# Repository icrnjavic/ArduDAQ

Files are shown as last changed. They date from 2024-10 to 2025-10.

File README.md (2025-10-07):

# ArduDAQ

<p float="left">
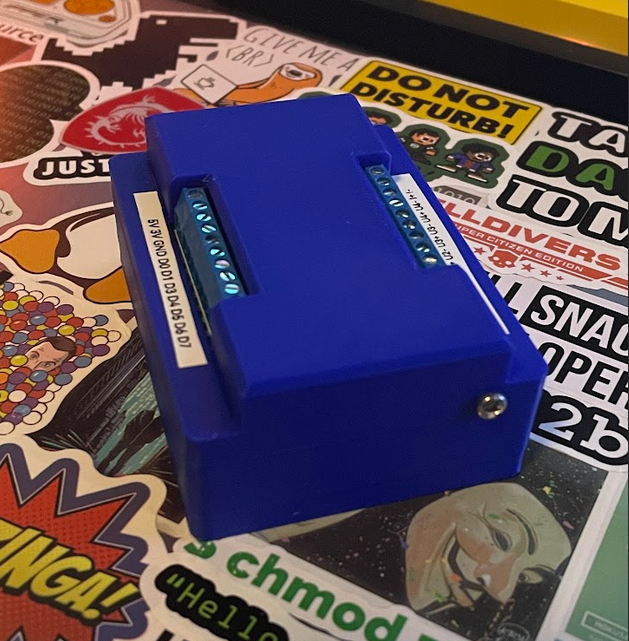
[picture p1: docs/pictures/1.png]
  
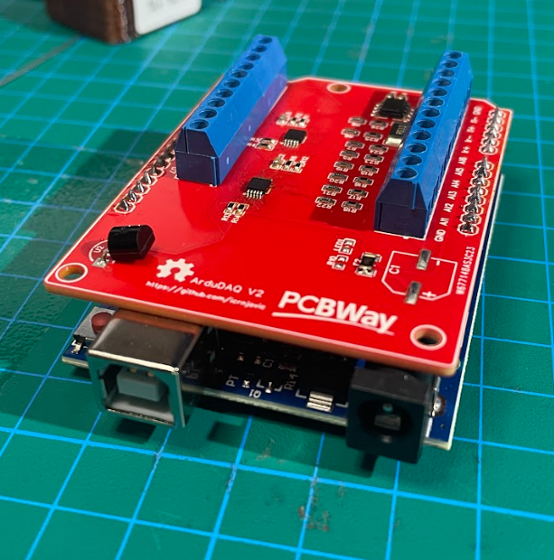
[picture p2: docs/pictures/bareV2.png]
  
</p>

***ArduDAQ*** is an open-source data acquisition shield for the popular Arduino platform with design to measure voltage, current, and onboard temperature with access to the rest of the pins from the base board for IO control. <br>
Now also comes with a stackable partner board that can turn the ArduDAQ into a bench multimeter for a more "plug and play" use directly with test probes and the companion Desktop App.  <br>
<p float="left">
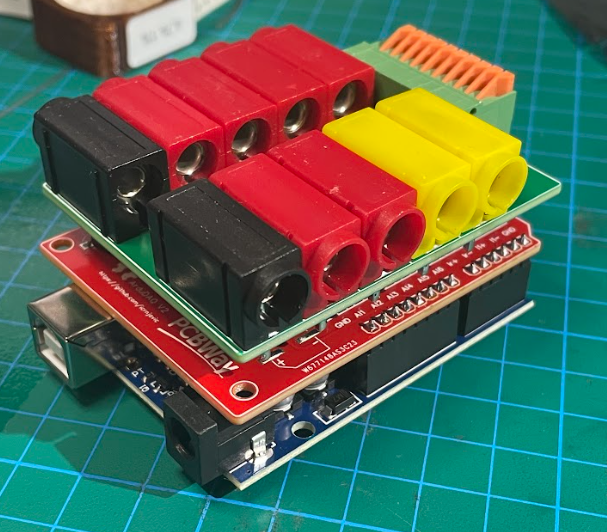
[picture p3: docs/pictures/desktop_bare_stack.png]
  
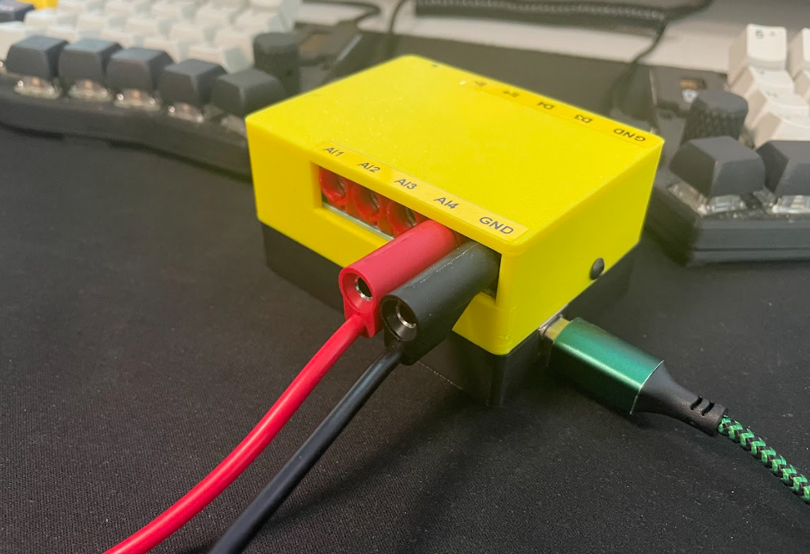
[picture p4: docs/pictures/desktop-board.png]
  
</p>

## Sponsor
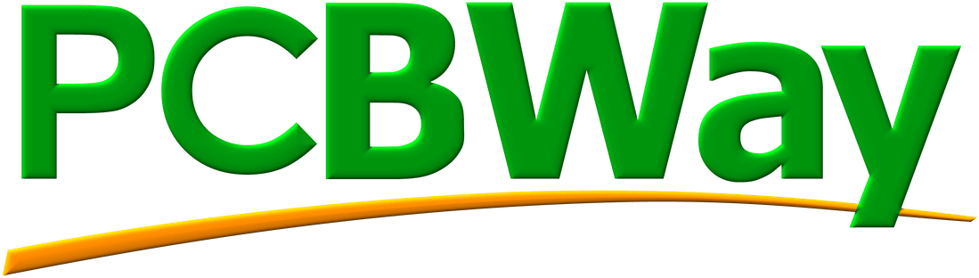
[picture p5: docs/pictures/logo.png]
PCBWay
 has graciously sponsored the V2 and Desktop Carrier Board.  

The hardware for this project is open source, and you can easily order the PCBs directly from PCBWay through the following [link](https://www.pcbway.com/project/shareproject/ArduDAQ_V2_Arduino_Data_acquisition_shield_hat_7666eddc.html) without the hassle of dealing with Gerber files.  

I highly recommend their services. I’ve been using PCBWay for a long time, and they have always delivered high-quality products and excellent support.

## Specifications

| Spec | info |
|---|---|
| Up to 8 AIN pins| By default has 6 analog inputs but can be configured up to 8.<br>16bit @ 860SPS. |
| Up to 2 current channels| Hall effect based channel up to(not recommended) 5A via internal 10bit ADC.<br>Shunt channel configurable with 16bit @ 860SPS. |
| 7 outputs| 7 digital outputs; 4 of which are PWM pins. |
| Onboard temp.| ds18b20 offers great accuracy and is often included in arduino kits so it was chosen over the NTC route|

## Dekstop App
Alongside ArduDAQ shield's support for serial commands for automated measurements it also has a desktop app.<br>
It will be able to put the ArduDAQ in continuous mode to display measured voltages on selected voltage channels over time and plot those measurements.</br>
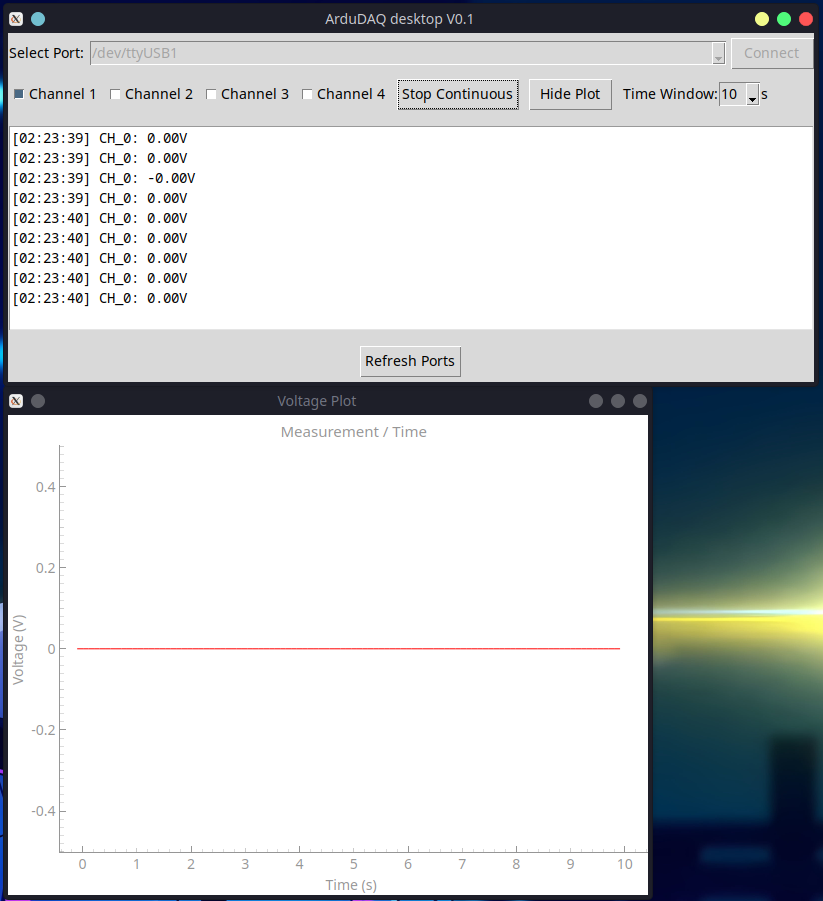
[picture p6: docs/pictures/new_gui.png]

</br>

</br>Watch a short demo of the app:</br>
Watch here (https://www.youtube.com/watch?v=IrxwRATrHMw)

## Versions/releases

| Version | HW/FW/SW | Comments |
|---|---|---|
| Desktop v1| HW | Carrier board that turrns the ArduDAQ into a more plug and play dekstop multimeter when paired with the Desktop app. Compatible with both V1 and V2 HW.|
| v2 | HW&FW | V2 features up to 4 more 16bit input, additional current input with better low current accuracy.|
| v1 | HW | HW fixes for IO pins |
| Desktop app v1| SW  | PC app for reading-plotting data in real time.|
| v0.1 | HW&FW | Initial release of ArduDAQ |
<br>

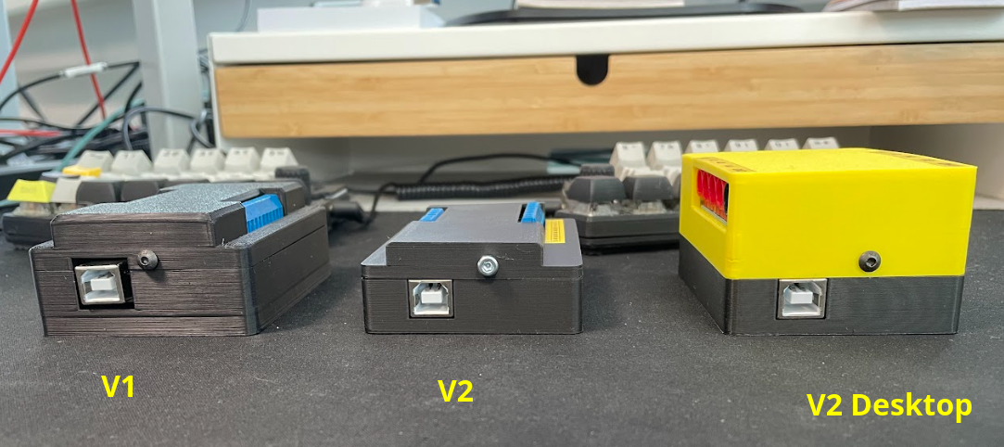
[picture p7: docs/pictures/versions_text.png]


## Usage & docs
For usage with examples and more details read the [documentation](docs/usage_documentation.md).

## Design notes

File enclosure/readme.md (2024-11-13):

Files also availible on thingiverse and printables.<br>
Thingiverse: https://www.thingiverse.com/thing:6830538 <br>
Pritnables: https://www.printables.com/model/1072373-ardudaq-enclosure-for-the-arduino-data-acquisition

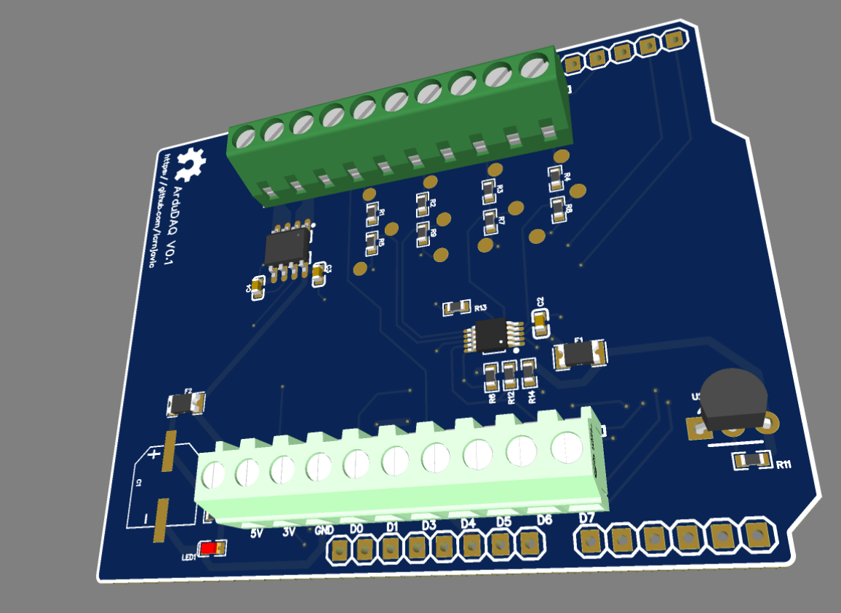
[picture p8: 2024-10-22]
docs/pictures/3d_model.png

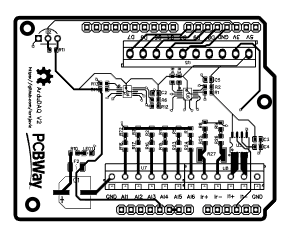
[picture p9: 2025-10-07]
docs/V2 docs/PCB_ArduDAQ-V2.png

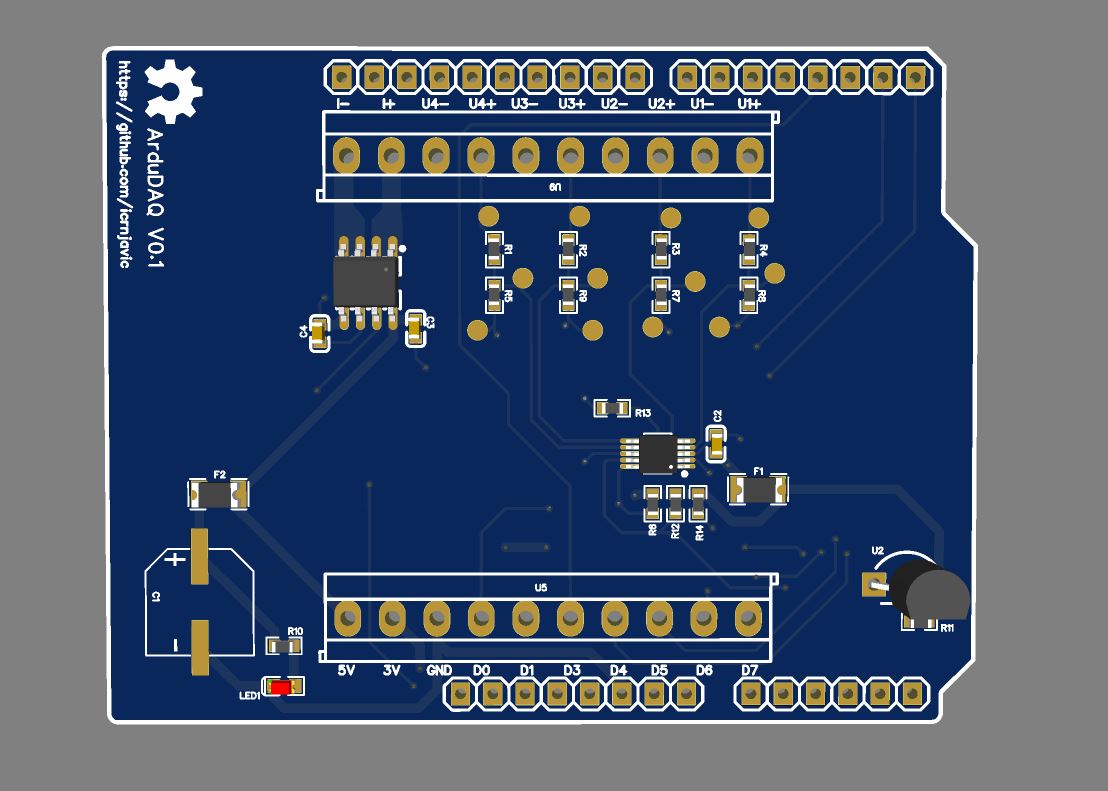
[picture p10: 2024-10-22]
docs/pictures/pcb_top_side.JPG

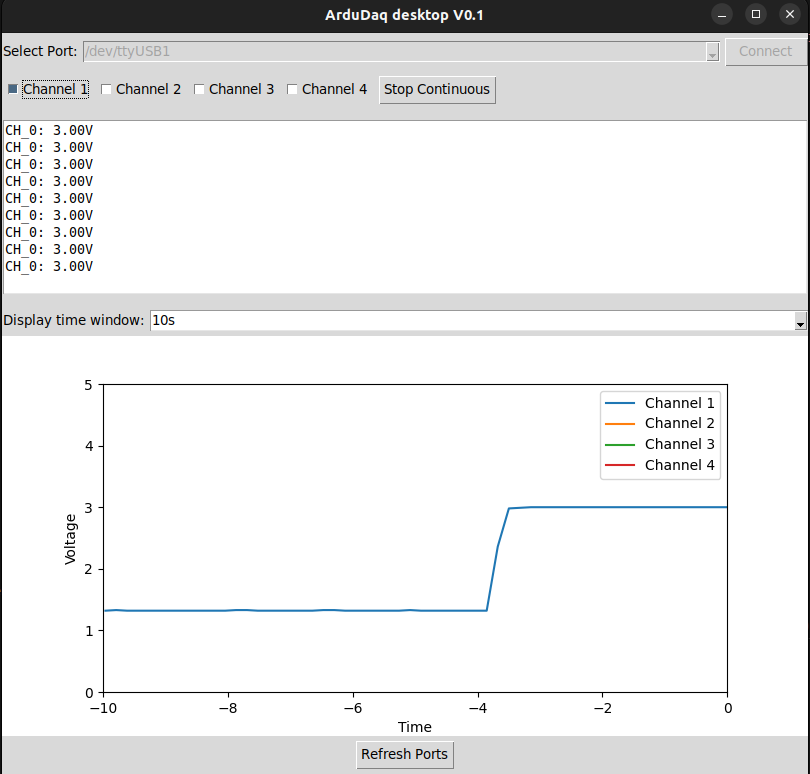
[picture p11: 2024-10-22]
docs/pictures/desktop_app.png

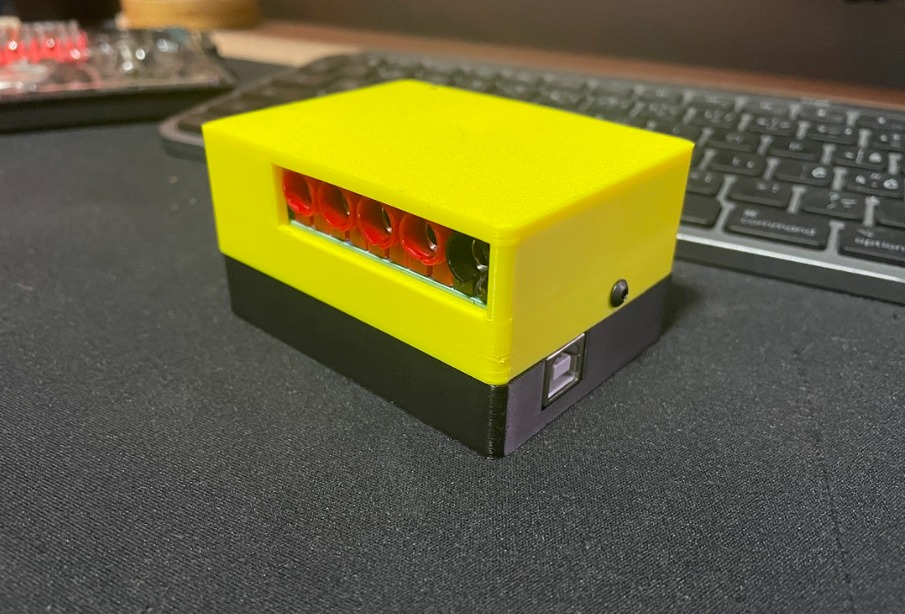
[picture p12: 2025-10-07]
docs/pictures/desktop-board2.png

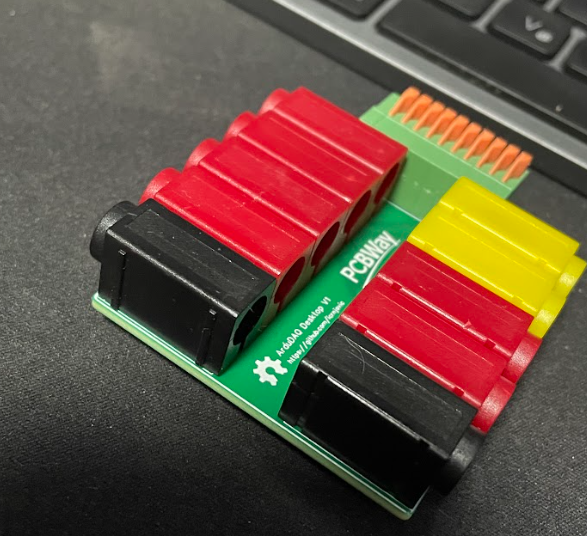
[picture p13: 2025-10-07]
docs/pictures/desktop_base.png

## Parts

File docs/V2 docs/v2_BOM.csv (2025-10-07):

Component | Designator | Footprint | Quantity | Manufacturer Part | Manufacturer | Supplier | Supplier Part | Price
0.1uF | C2,C3,C5 | C0603 | 3 | 0603CG0R1B500NT | FH(风华) | LCSC | C2894312 | 0.006
1nF | C4 | C0603 | 1 | 0603CG0R1B500NT | FH(风华) | LCSC | C2894312 | 0.006
1A Fuse | F2 | FUSE-SMD_L3.5-W1.9 | 1 | SMD1206-012/60N | BORN(伯恩半导体) | LCSC | C6165184 | 0.036
10k | R1,R2,R3,R4,R6,R12,R13,R14 | R0603 | 8 | SCR0603J10K | VO(翔胜) | LCSC | C3017715 | 0.001
1kΩ | R5,R7,R8,R9,R19,R20,R21,R22 | R0603 | 8 | HoARG0603-1/10W-1KR-0.1%-TCR25 | Milliohm(毫欧) | LCSC | C5123612 | 0.049
4.7k | R11 | R0603 | 1 | HoARG0603-1/10W-1KR-0.1%-TCR25 | Milliohm(毫欧) | LCSC | C5123612 | 0.049
10kΩ | R15,R16,R17,R18,R23,R24,R25,R26 | R0603 | 8 | SCR0603J10K | VO(翔胜) | LCSC | C3017715 | 0.001
1R | R27 | R2512 | 1
DS18B20+T&R | U2 | TO-92-3_L4.9-W3.7-P2.54-L | 1 | DS18B20+T&R | ADI(亚德诺)/MAXIM(美信) | LCSC | C880672 | 1.469
ACS712ELCTR-05B | U3 | SOP-8_L4.9-W3.9-P1.27-LS6.0-BL | 1 | ACS712ELCTR-05B | ALLEGRO(美国埃戈罗) | LCSC | C18390
ADS1115IDGSR | U4,U6 | MSOP-10_L3.0-W3.0-P0.50-LS5.0-BL | 2 | ADS1115IDGSR | TI(德州仪器) | LCSC | C37593 | 0.898
KF350-3.5-10P | U5 | CONN-TH_3P-P3.50_KF350-3.5-10P | 1 | KF350-3.5-3P | Cixi Kefa Elec | LCSC | C474893 | 0.145
WJ350V-3.5-6P | U7,U8 | CONN-TH_6P-P3.50_WJ350V-3.5-6P | 2 | WJ350V-3.5-6P | KANGNEX(康奈克斯电气) | LCSC | C42377765 | 0.332

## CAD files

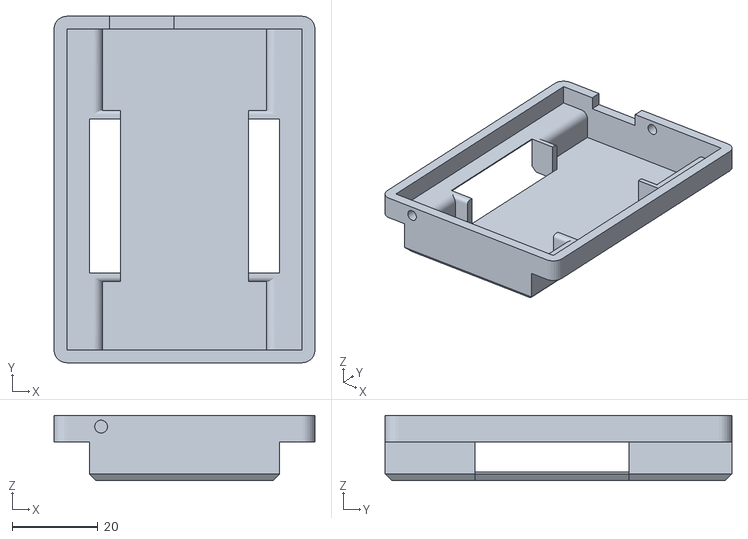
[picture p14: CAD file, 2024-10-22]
enclosure/V1/ardudaqcase_top.stl
61.0 x 81.0 x 15.2

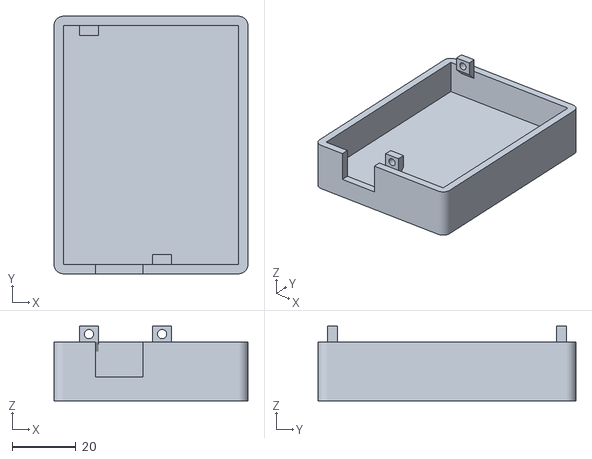
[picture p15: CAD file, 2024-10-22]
enclosure/V1/ardudaqcase-bot.stl
61.0 x 81.0 x 23.5

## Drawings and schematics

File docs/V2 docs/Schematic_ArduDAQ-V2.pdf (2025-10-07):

# External ADCs

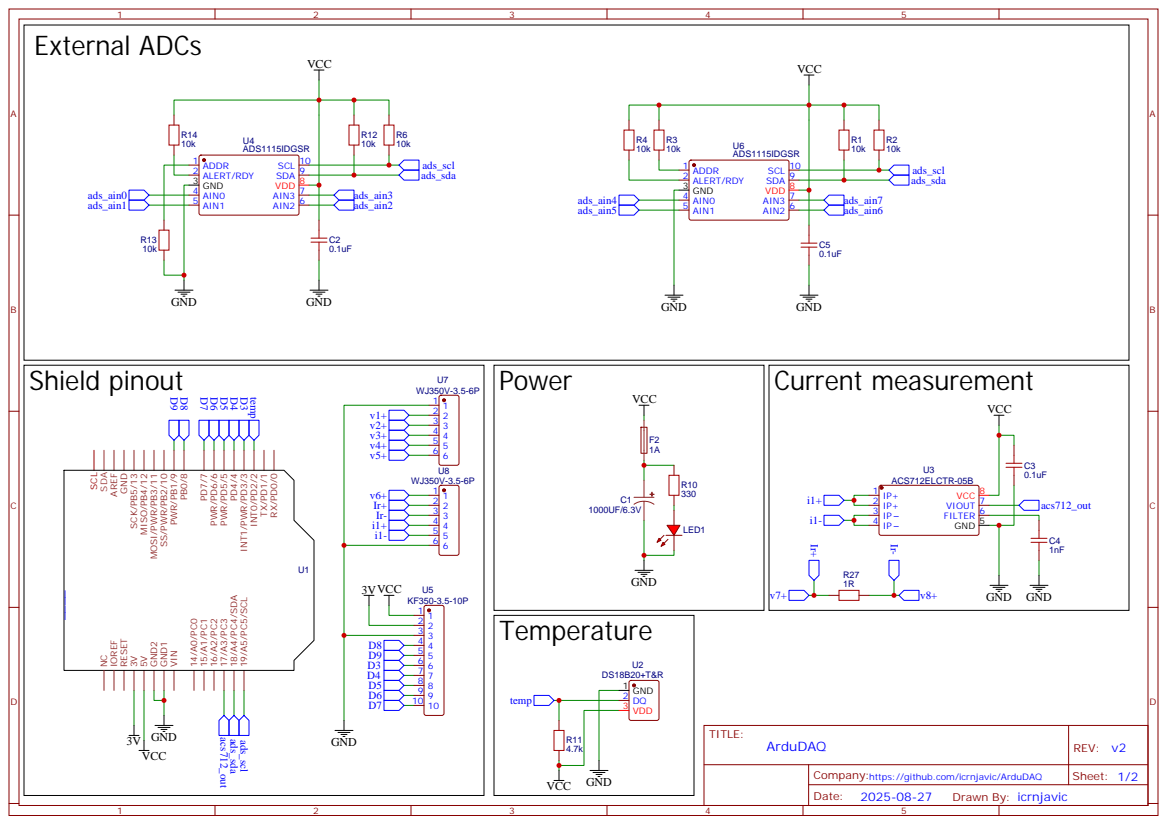
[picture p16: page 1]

Company:https://github.com/icrnjavic/ArduDAQ

# ADC dividers

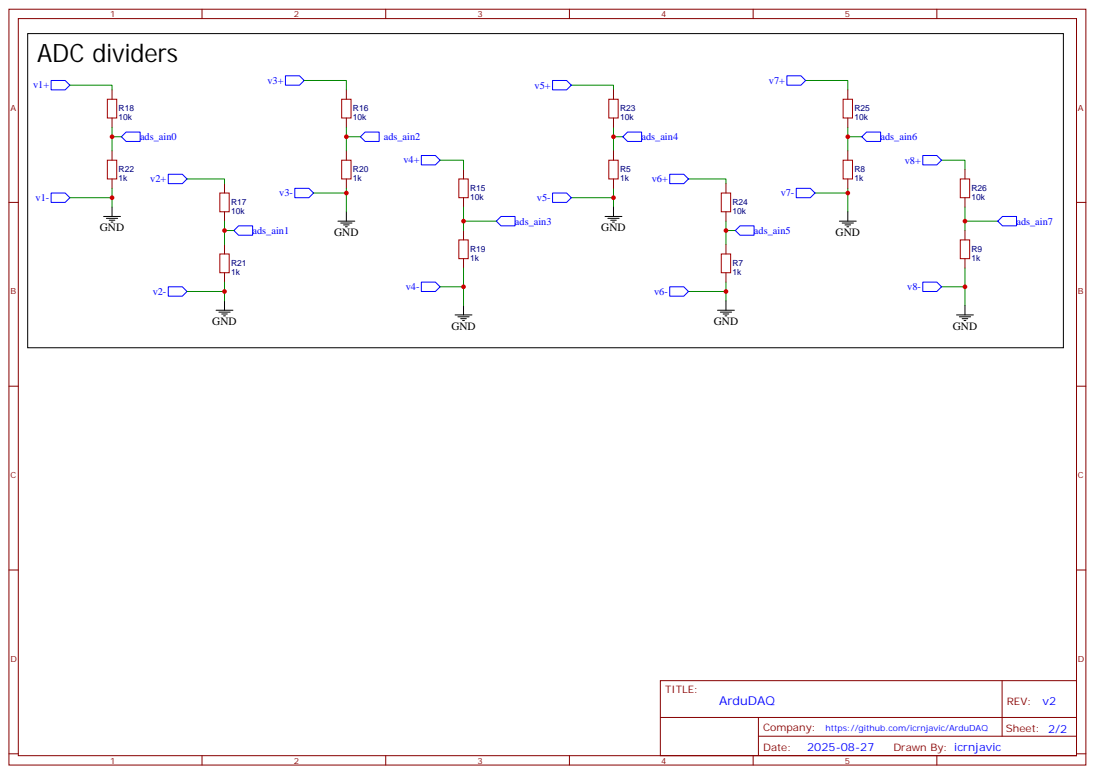
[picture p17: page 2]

Company: https://github.com/icrnjavic/ArduDAQ

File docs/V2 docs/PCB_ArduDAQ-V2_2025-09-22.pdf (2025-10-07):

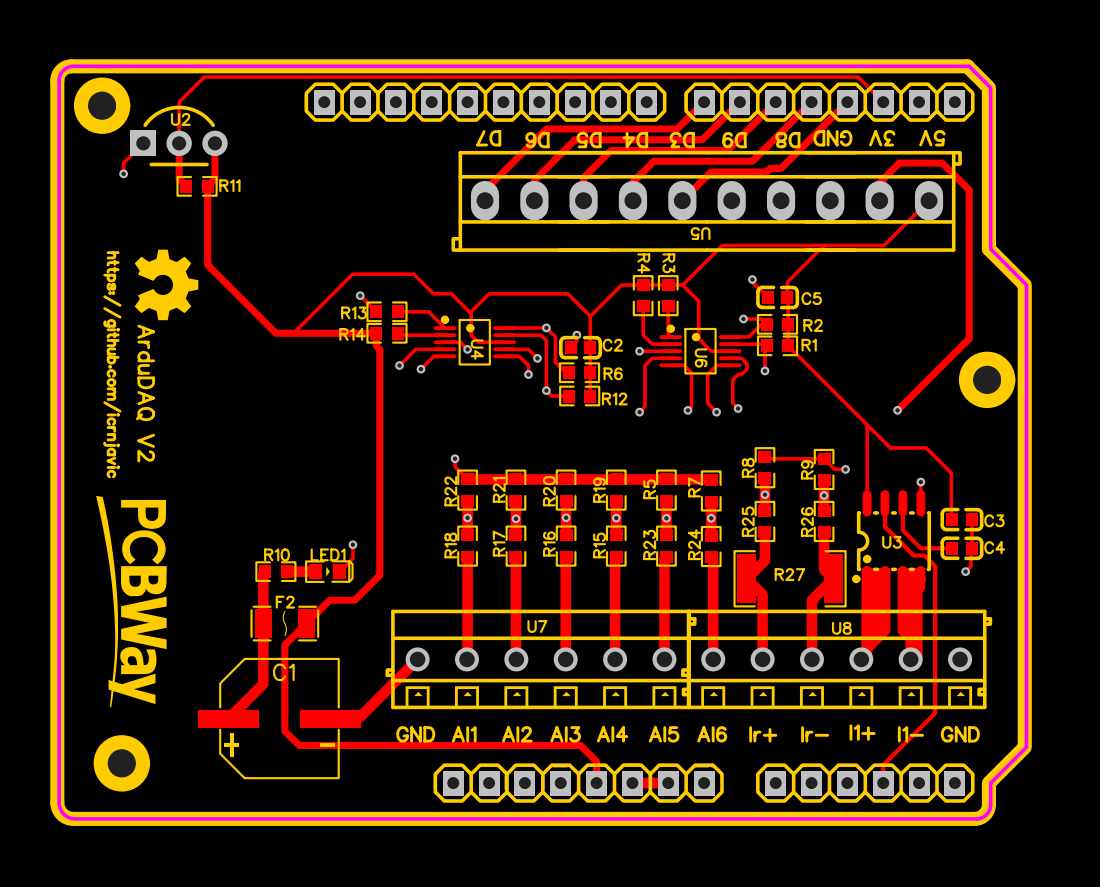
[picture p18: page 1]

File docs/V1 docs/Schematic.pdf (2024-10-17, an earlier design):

# Voltage measurements

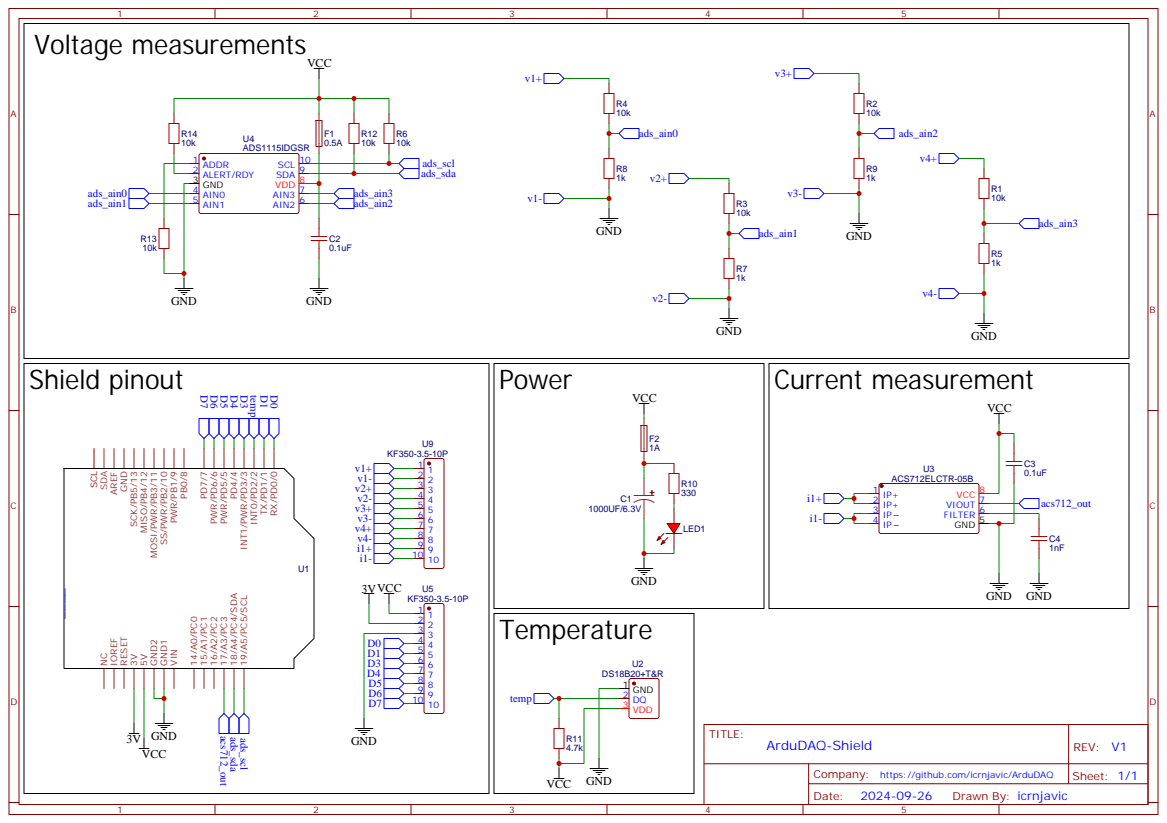
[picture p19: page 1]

Company: https://github.com/icrnjavic/ArduDAQ

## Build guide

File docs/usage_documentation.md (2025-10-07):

## Getting Started

### Serial Communication
- **Baud Rate**: 115200
- **Data Bits**: 8
- **Parity**: None
- **Stop Bits**: 1
- **Flow Control**: None

### Supported commands
| Command | Description | Response Format |
|---|---|---|
| `*IDN?` | Request device identification | Device identifier  |
| `MEAS:VOLT:CHAN1?`| Read voltage from channel 1 | `<value>` in V |
| `MEAS:VOLT:CHAN2?`| Read voltage from channel 2 | `<value>` in V |
| `MEAS:VOLT:CHAN3?`| Read voltage from channel 3 | `<value>` in V |
| `MEAS:VOLT:CHAN4?`| Read voltage from channel 4 | `<value>` in V |
| `MEAS:CURR?` | Read current measurement | `<value>` in A |
| `MEAS:TEMP?` | Read temperature measurement | `<value>` in °C|
| `OUTP:CHAN3 ON` | Turn on channel 3 output | Channel 3 ON |
| `OUTP:CHAN3 OFF`  | Turn off channel 3 output | Channel 3 OFF |
| `OUTP:CHAN4 ON` | Turn on channel 4 output | Channel 4 ON |
| `OUTP:CHAN4 OFF`  | Turn off channel 4 output | Channel 4 OFF |
| `OUTP:CHAN5 ON` | Turn on channel 5 output | Channel 5 ON |
| `OUTP:CHAN5 OFF`  | Turn off channel 5 output | Channel 5 OFF |
| `OUTP:CHAN6 ON` | Turn on channel 6 output | Channel 6 ON |
| `OUTP:CHAN6 OFF`  | Turn off channel 6 output | Channel 6 OFF |
| `OUTP:CHAN7 ON` | Turn on channel 7 output | Channel 7 ON |
| `OUTP:CHAN7 OFF`  | Turn off channel 7 output | Channel 7 OFF |

### Example Usage

To read the voltage on Channel 1, send the command `MEAS:VOLT:CHAN1?` over serial. Board will respond with a message like: `3.3001V`

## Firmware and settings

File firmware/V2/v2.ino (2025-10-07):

//
// https://github.com/icrnjavic/ArduDAQ
// Arduino shield for data acquisition of voltage, current and temperature.
// Version 2.0 - Dual ADS1115 support and an extra current measurement input via shunt (8 channels total; 2 inputs will be used for current measurement via shunt)
// Version 2.1.2 - All 8 ads channels usable as analog inputs with 2 being configurable to use for current measurements via onboard shunt
//


const String FIRMWARE_VERSION = "2.1.2";

#include <Wire.h>
#include <Adafruit_ADS1X15.h>
#include <OneWire.h>
#include <DallasTemperature.h>

Adafruit_ADS1115 ads1;  // 0x48
Adafruit_ADS1115 ads2;  // 0x49

// divider values per channel (1–8)
float R1[8] = {10000,10000,10000,10000,10000,10000,10000,10000};
float R2[8] = {1000,1000,1000,1000,1000,1000,1000,1000};

// DS18B20
#define ONE_WIRE_BUS 2
OneWire oneWire(ONE_WIRE_BUS);
DallasTemperature sensors(&oneWire);

// ACS712-5A (internal ADC path)
float ACS712_Offset = 2.5;
float ACS712_Sensitivity = 0.185;  // V/A
float currentDeadband = 0.05;      // V (ACS path only)

// --- Shunt setup (default 10 mΩ) ---
// makes it configurable at runtime:
float SHUNT_RESISTANCE = 0.01f;          // Ω
const float ADS1115_LSB_V_GAIN16 = 0.0000078125f; // 7.8125 µV/LSB
float shuntZeroOffset_V = 0.0f;          // V after zeroing
float shuntDeadband_mA  = 0.8f;          // ignore tiny jitter
float shuntScale        = 1.0f;          // multiplicative scale correction
bool  shuntInvert       = false;         // invert sign if wiring flipped

bool continuousMode = false;
unsigned long lastMeasurementTime = 0;
const unsigned long measurementInterval = 10;

bool isValidChannel(int channel) { return channel >= 0 && channel < 8; }
// only allow D3–D9 as digital outputs (avoid D0/D1 serial pins!)
bool isValidPin(int pin) { return (pin == 3 || pin == 4 || pin == 5 || pin == 6 || pin == 7 || pin == 8 || pin == 9); }

void setup() {
  Serial.begin(115200);
  delay(200);
  Serial.println();
  Serial.println(F("ArduDAQ v2.1.2 – ready @115200"));

  if (!ads1.begin(0x48)) { Serial.println(F("Failed to init ADS1115 #1 (0x48)!")); while (1) {} }
  if (!ads2.begin(0x49)) { Serial.println(F("Failed to init ADS1115 #2 (0x49)!")); while (1) {} }

  sensors.begin();

  // Configure output pins (D3–D9 only)
  pinMode(3, OUTPUT); pinMode(4, OUTPUT); pinMode(5, OUTPUT); pinMode(6, OUTPUT); pinMode(7, OUTPUT); pinMode(8, OUTPUT); pinMode(9, OUTPUT);
  digitalWrite(3, LOW); digitalWrite(4, LOW); digitalWrite(5, LOW); digitalWrite(6, LOW); digitalWrite(7, LOW); digitalWrite(8, LOW); digitalWrite(9, LOW);

  calibrateACS712Offset();

  // Default gains/rates for voltage channels
  ads1.setGain(GAIN_ONE);  // ±4.096 V
  ads2.setGain(GAIN_ONE);  // ±4.096 V
  ads1.setDataRate(RATE_ADS1115_860SPS);
  ads2.setDataRate(RATE_ADS1115_860SPS);

  calibrateShuntOffset();

  Serial.println(F("Init done. Type 'info' for commands."));
}

void loop() {
  if (Serial.available() > 0) {
    String command = Serial.readStringUntil('\n');
    processCommand(command);
  }
  if (continuousMode && (millis() - lastMeasurementTime >= measurementInterval)) {
    sendContinuousMeasurements();
    lastMeasurementTime = millis();
  }
}

static inline String upcase(const String &s) {
  String t = s; t.toUpperCase(); return t;
}

void processCommand(String command) {
  command.trim();
  String U = upcase(command);

  if (U.startsWith("OUTP")) {
    int pIdx = U.indexOf("PIN=");
    if (pIdx >= 0 && pIdx + 6 <= (int)U.length()) {
      int pin = U.substring(pIdx + 4, pIdx + 6).toInt();
      if (!isValidPin(pin)) { Serial.println(F("Invalid pin (use 3,4,5,6,7)")); return; }
      if (U.endsWith("ON"))  { digitalWrite(pin, HIGH); Serial.print(F("Pin D")); Serial.print(pin); Serial.println(F(" HIGH")); }
      else if (U.endsWith("OFF")) { digitalWrite(pin, LOW);  Serial.print(F("Pin D")); Serial.print(pin); Serial.println(F(" LOW")); }
      else { Serial.println(F("Invalid OUTP command")); }
    } else {
      Serial.println(F("Format: OUTP:PIN=03:ON|OFF"));
    }

  } else if (U == "INFO") {
    Serial.println(F("Commands:"));
    Serial.println(F("  OUTP:PIN=03:ON|OFF"));
    Serial.println(F("  MEAS:VOLT:CHAN1? .. :CHAN8?"));
    Serial.println(F("  MEAS:CURR?                 (ACS712, A)"));
    Serial.println(F("  MEAS:CURR:SHUNT?           (mA numeric)"));
    Serial.println(F("  MEAS:CURR:SHUNT:TXT?       (mA with units)"));
    Serial.println(F("  MEAS:CURR:SHUNT:RAW?       (debug raw, µV)"));
    Serial.println(F("  MEAS:CURR:SHUNT:ZERO       (re-zero shunt)"));
    Serial.println(F("  CONF:SHUNT:R=<ohms>        (e.g. 0.01)"));
    Serial.println(F("  CONF:SHUNT:SCALE=<factor>  (e.g. 1.000)"));
    Serial.println(F("  CONF:SHUNT:INV=ON|OFF      (invert sign)"));
    Serial.println(F("  MEAS:TEMP?"));
    Serial.println(F("  START_CONTINUOUS / STOP_CONTINUOUS"));
    Serial.println(F("  VERSION"));

  } else if (U == "VERSION") {
    Serial.print(F("Firmware Version: ")); Serial.println(FIRMWARE_VERSION);

  } else if (U == "START_CONTINUOUS") {
    continuousMode = true;  Serial.println(F("Continuous mode started"));

  } else if (U == "STOP_CONTINUOUS") {
    continuousMode = false; Serial.println(F("Continuous mode stopped"));

  } else if (U == "MEAS:VOLT:CHAN1?") { Serial.println(readChannelVoltage(0), 4);
  } else if (U == "MEAS:VOLT:CHAN2?") { Serial.println(readChannelVoltage(1), 4);
  } else if (U == "MEAS:VOLT:CHAN3?") { Serial.println(readChannelVoltage(2), 4);
  } else if (U == "MEAS:VOLT:CHAN4?") { Serial.println(readChannelVoltage(3), 4);
  } else if (U == "MEAS:VOLT:CHAN5?") { Serial.println(readChannelVoltage(4), 4);
  } else if (U == "MEAS:VOLT:CHAN6?") { Serial.println(readChannelVoltage(5), 4);
  } else if (U == "MEAS:VOLT:CHAN7?") { Serial.println(readChannelVoltage(6), 4);
  } else if (U == "MEAS:VOLT:CHAN8?") { Serial.println(readChannelVoltage(7), 4);

  } else if (U == "MEAS:CURR?") {
    Serial.println(readCurrentAverage(), 4); // Amps (ACS712)

  } else if (U == "MEAS:CURR:SHUNT?") {
    Serial.println(readShuntCurrentAverage_mA(), 3); // mA (shunt)
    /*──────────────────────────────────────────────────────────────────────────────
      SHUNT CURRENT MEASUREMENT – QUICK GUIDE (ADS1115, 10 mΩ default)

      Overview
      - The shunt is read DIFFERENTIALLY (ADS #2, A2–A3) at GAIN_SIXTEEN (±0.256 V).
      - Resolution at this gain is 7.8125 µV/LSB.
      - With a 10 mΩ shunt: 1 mA → 10 µV, so ≈0.781 mA/LSB (7.8125 µV / 10 µV).
        After averaging 32 samples, effective noise is ~0.14–0.2 mA.

      Default Settings (can be changed via serial commands below)
      - SHUNT_RESISTANCE = 0.01 Ω  (10 mΩ)
      - shuntScale       = 1.0      (unitless fine calibration)
      - shuntInvert      = OFF      (polarity normal)
      - shuntZeroOffset  = measured at startup (do MEAS:CURR:SHUNT:ZERO if needed)
      - Deadband         = 0.8 mA   (suppress tiny jitter around 0)

      Commands (type in Serial Monitor @115200 baud)
      - MEAS:CURR:SHUNT?         → numeric current in mA (no units; machine-friendly)
      - MEAS:CURR:SHUNT:TXT?     → current in mA with units (e.g., "59.982 mA")
      - MEAS:CURR:SHUNT:RAW?     → debug: raw counts + microvolts (before/after zero)
      - MEAS:CURR:SHUNT:ZERO     → re-measure & store zero-offset (no load connected)
      - CONF:SHUNT:R=<ohms>      → set shunt value (e.g., 0.01, 0.1, 1.0)
      - CONF:SHUNT:SCALE=<k>     → fine scale factor (e.g., 1.012 for +1.2%)
      - CONF:SHUNT:INV=ON|OFF    → invert sign if wiring is flipped

      One-Minute Calibration Procedure (recommended)
      1) Warm up for 30–60 s. Disconnect load. Send: MEAS:CURR:SHUNT:ZERO
      2) Apply a known current (e.g., 60.00 mA measured on a DMM).
      3) Read MEAS:CURR:SHUNT?  (e.g., returns 58.0)
      4) Set fine scale: CONF:SHUNT:SCALE= (known_mA / measured_mA)
        Example: 60.00 / 58.0 = 1.03448 → CONF:SHUNT:SCALE=1.03448
      5) (Optional) If sign is negative, send: CONF:SHUNT:INV=ON

      When to change R vs SCALE
      - R (ohms) = the physics. Use this if the reading is off by 2×, 10×, 100×
        (e.g., board has 0.1 Ω instead of 0.01 Ω). Command: CONF:SHUNT:R=0.1
      - SCALE (unitless) = small trim (±0–5%) to correct tolerance/gain/layout error
        after R is correct. Command: CONF:SHUNT:SCALE=1.02 (for +2%)

      Using RAW for sanity checks
      - MEAS:CURR:SHUNT:RAW? prints: raw counts, v_raw (µV), v_zero (µV after zero).
      - For a 10 mΩ shunt, each 1 mA corresponds to ~10 µV across the shunt.
        So at ~60 mA you expect ~600 µV (≈ 600 / 7.8125 ≈ 77 counts).
      - If v_zero matches expectation but current looks 10× off, fix R (not SCALE).

      Expected Numbers (10 mΩ reference)
      - 10 mA  → ~100 µV across shunt → ~13 counts → ~10 mA reported
      - 60 mA  → ~600 µV across shunt → ~77 counts → ~60 mA reported
      - 100 mA → ~1,000 µV (~1.0 mV)   → ~128 counts → ~100 mA reported

      Stability Tips
      - Re-zero after thermal changes: MEAS:CURR:SHUNT:ZERO (no load).
      - If you ever see noise spikes at very low currents, increase averaging
        (code uses 32 samples) or increase the deadband slightly.
      - Keep shunt wiring as Kelvin (4-wire) to the ADC inputs for best accuracy.

      Output/Units
      - MEAS:CURR:SHUNT? returns numeric mA (no units) for easy parsing.
      - MEAS:CURR:SHUNT:TXT? returns a human-friendly string with " mA".
    ──────────────────────────────────────────────────────────────────────────────*/


  } else if (U == "MEAS:CURR:SHUNT:TXT?") {
    float mA = readShuntCurrentAverage_mA();
    Serial.print(mA, 3); Serial.println(F(" mA"));

  } else if (U == "MEAS:CURR:SHUNT:RAW?") {
    // One-shot raw debug: counts & microvolts (before/after zero)
    ads2.setGain(GAIN_SIXTEEN);
    int16_t raw = ads2.readADC_Differential_2_3();
    float v_raw = raw * ADS1115_LSB_V_GAIN16;        // V
    float v_zeroed = v_raw - shuntZeroOffset_V;      // V
    Serial.print(F("raw=")); Serial.print(raw);
    Serial.print(F(", v_raw="));   Serial.print(v_raw * 1e6, 1);   Serial.print(F(" uV"));
    Serial.print(F(", v_zero="));  Serial.print(v_zeroed * 1e6, 1); Serial.println(F(" uV"));

  } else if (U == "MEAS:CURR:SHUNT:ZERO") {
    calibrateShuntOffset();
    Serial.print(F("Shunt zero (V): ")); Serial.println(shuntZeroOffset_V, 6);

  } else if (U.startsWith("CONF:SHUNT:R=")) {
    String v = command.substring(13); v.trim();
    float newR = v.toFloat();
    if (newR > 0.0f && newR < 100.0f) { SHUNT_RESISTANCE = newR; Serial.print(F("SHUNT R=")); Serial.println(SHUNT_RESISTANCE, 5); }
    else { Serial.println(F("Invalid R (ohms)")); }

  } else if (U.startsWith("CONF:SHUNT:SCALE=")) {
    String v = command.substring(17); v.trim();
    float s = v.toFloat();
    if (s > 0.01f && s < 100.0f) { shuntScale = s; Serial.print(F("SHUNT SCALE=")); Serial.println(shuntScale, 6); }
    else { Serial.println(F("Invalid SCALE")); }

  } else if (U.startsWith("CONF:SHUNT:INV=")) {
    if (U.endsWith("ON"))  { shuntInvert = true;  Serial.println(F("SHUNT INV=ON")); }
    else if (U.endsWith("OFF")) { shuntInvert = false; Serial.println(F("SHUNT INV=OFF")); }
    else { Serial.println(F("Use CONF:SHUNT:INV=ON|OFF")); }

  } else if (U == "MEAS:TEMP?") {
    Serial.println(readTemperature(), 2);

  } else if (U.startsWith("READ_CHANNEL_")) {
    int channel = command.substring(13).toInt();
    if (isValidChannel(channel)) { Serial.println(readChannelVoltage(channel), 4); }
    else { Serial.println(F("Invalid channel")); }

  } else {
    Serial.println(F("Unknown command. Type 'info'."));
  }
}

void sendContinuousMeasurements() {
  String response = "";
  for (int i = 0; i < 4; i++) {
    response += "CH_";
    response += String(i);
    response += ": ";
    response += String(readChannelVoltage(i), 4);
    response += "V, ";
  }
  response.trim();
  Serial.println(response);
}

// -------- voltage channels (external ADC inputs) --------
float readChannelVoltage(int channel) {
  int16_t adcReading;
  float Vout, inputVoltage;
  Adafruit_ADS1115* ads;
  int adsChannel;

  if (channel < 4) { ads = &ads1; adsChannel = channel; }
  else             { ads = &ads2; adsChannel = channel - 4; }

  ads->setGain(GAIN_TWOTHIRDS);
  adcReading = ads->readADC_SingleEnded(adsChannel);
  Vout = (adcReading * 6.144f) / 32767.0f;
  inputVoltage = Vout * ((R1[channel] + R2[channel]) / R2[channel]);

  if (inputVoltage < 4.0f) {
    ads->setGain(GAIN_ONE);
    adcReading = ads->readADC_SingleEnded(adsChannel);
    Vout = (adcReading * 4.096f) / 32767.0f;
    inputVoltage = Vout * ((R1[channel] + R2[channel]) / R2[channel]);
  }
  return inputVoltage;
}

// -------- ACS712 (suitable  mostly for rough 1-2A loads) --------
float readCurrentAverage() {
  const int numMeasurements = 20;
  float totalCurrent = 0;
  for (int i = 0; i < numMeasurements; i++) {
    totalCurrent += readCurrent();
    delay(5);
  }
  return totalCurrent / numMeasurements; // A
}

float readCurrent() {
  int16_t currentAdcReading = analogRead(A3);
  float currentVout = (currentAdcReading * 5.0f) / 1023.0f;
  return (currentVout - ACS712_Offset) / ACS712_Sensitivity; // A
}

void calibrateACS712Offset() {
  float total = 0;
  const int numReadings = 100;
  for (int i = 0; i < numReadings; i++) {
    total += (analogRead(A3) * 5.0f) / 1023.0f;
    delay(5);
  }
  ACS712_Offset = total / numReadings;
}

// -------- shunt via ADS1115 differential @ high gain --------
float readShuntDiff_V_once() {
  ads2.setGain(GAIN_SIXTEEN); // ±0.256 V
  int16_t raw = ads2.readADC_Differential_2_3(); // A2 - A3
  float v = raw * ADS1115_LSB_V_GAIN16; // V
  return (v - shuntZeroOffset_V);
}

float readShuntCurrent_mA_once() {
  float v = readShuntDiff_V_once();
  float mA = (v / SHUNT_RESISTANCE) * 1000.0f;
  if (shuntInvert) mA = -mA;
  mA *= shuntScale;
  if (fabs(mA) < shuntDeadband_mA) mA = 0.0f;
  return mA;
}

float readShuntCurrentAverage_mA() {
  const int N = 32;
  float sum = 0;
  for (int i = 0; i < N; i++) {
    sum += readShuntCurrent_mA_once();
    delay(3);
  }
  return sum / N;
}

void calibrateShuntOffset() {
  const int N = 64;
  float acc = 0;
  ads2.setGain(GAIN_SIXTEEN);
  for (int i = 0; i < N; i++) {
    int16_t raw = ads2.readADC_Differential_2_3();
    acc += raw * ADS1115_LSB_V_GAIN16;
    delay(3);
  }
  shuntZeroOffset_V = acc / N;
}

// -------- Temperature --------
float readTemperature() {
  sensors.requestTemperatures();
  return sensors.getTempCByIndex(0);
}

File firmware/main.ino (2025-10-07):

//
// https://github.com/icrnjavic/ArduDAQ
// Arduino shield for data aquisiton of voltage, current and temperature measurements with available IO from teh ebase board.
// Version 2.0 - Dual ADS1115 support and an extra current measurement input via shunt (8 channels total; 2 inputs will be used for current measurement via shunt)
//

// fw version
const String FIRMWARE_VERSION = "2.0";



#include <Wire.h>
#include <Adafruit_ADS1X15.h>
#include <OneWire.h>
#include <DallasTemperature.h>

Adafruit_ADS1115 ads1;  // first ADS1115 (addr pulled to ground = 0x48)
Adafruit_ADS1115 ads2;  // second ADS1115 (addr pulled to VCC = 0x49)

// array of voltage resistor values for individual channels 1-8 from left to right
float R1[8] = {10000.0, 10000.0, 10000.0, 10000.0, 10000.0, 10000.0, 10000.0, 10000.0};
float R2[8] = {1000.0, 1000.0, 1000.0, 1000.0, 1000.0, 1000.0, 1000.0, 1000.0};

// ds18b20 Temperature Sensor Setup
#define ONE_WIRE_BUS 2  // DS18B20 to pin D2
OneWire oneWire(ONE_WIRE_BUS);
DallasTemperature sensors(&oneWire);

// acs712-5A setup
float ACS712_Offset = 2.5;  
float ACS712_Sensitivity = 0.185;  // sensitivity for 5A version
float currentDeadband = 0.05;  // deadband noise filter

bool continuousMode = false;
unsigned long lastMeasurementTime = 0;
const unsigned long measurementInterval = 10;

#define SAMPLES_COUNT 64
#define SAMPLE_DELAY 0

// check if its a valid ads1115 channel(0-7)
bool isValidChannel(int channel) {
  return (channel >= 0 && channel < 8);
}

void setup() {
  Serial.begin(115200);
  if (!ads1.begin(0x48)) {
    Serial.println("Failed to initialize ADS1115 #1!");
    while (1);
  }
  if (!ads2.begin(0x49)) {
    Serial.println("Failed to initialize ADS1115 #2!");
    while (1);
  }
  //Serial.println("ADS1115 initialized.");
  //Serial.println("DS18B20 initialized.");
  sensors.begin();

  // set shield pins as outputs
  pinMode(0, OUTPUT); // wont work due to it being a serial pin -> usable for Tx/Rx usage
  pinMode(1, OUTPUT); // wont work due to it being a serial pin -> usable for Tx/Rx usage
  pinMode(3, OUTPUT);
  pinMode(4, OUTPUT);
  pinMode(5, OUTPUT);
  pinMode(6, OUTPUT);
  pinMode(7, OUTPUT);

  // set all output pins to LOW by default
  digitalWrite(0, LOW);
  digitalWrite(1, LOW);
  digitalWrite(3, LOW);
  digitalWrite(4, LOW);
  digitalWrite(5, LOW);
  digitalWrite(6, LOW);
  digitalWrite(7, LOW);

  // calibrate acs712 offset
  calibrateACS712Offset();

  ads1.setGain(GAIN_ONE);    // ±4.096V
  ads2.setGain(GAIN_ONE);    // ±4.096V
  
  // increase to maximum sample rate of 860 SPS (default is 128 SPS)
  ads1.setDataRate(RATE_ADS1115_860SPS);
  ads2.setDataRate(RATE_ADS1115_860SPS);
}

void loop() {
  if (Serial.available() > 0) {
    String command = Serial.readStringUntil('\n');
    processCommand(command);
  }

  if (continuousMode && (millis() - lastMeasurementTime >= measurementInterval)) {
    sendContinuousMeasurements();
    lastMeasurementTime = millis();
  }
}

void processCommand(String command) {
  if (command.startsWith("OUTP")) {
    String pinStr = command.substring(9, 11); // Extract from index 9 to 11
    int pin = pinStr.toInt(); // Convert to integer
    Serial.println(command);
    Serial.println(pin);

    if (isValidPin(pin)) {
      if (command.endsWith("ON")) {
        digitalWrite(pin, HIGH); // set extracted pin to HIGH
        Serial.print("Pin D");
        Serial.print(pin);
        Serial.println(" set to HIGH");
      } else if (command.endsWith("OFF")) {
        digitalWrite(pin, LOW); // set the extracted pin to LOW
        Serial.print("Pin D");
        Serial.print(pin);
        Serial.println(" set to LOW");
      } else {
        Serial.println("Invalid command");
      }
    } else {
      Serial.println("Invalid pin");
    }
  } else if (command.equals("info")) {
    Serial.println("SET_<pin_number>_ON - Sets the specified pin to HIGH.");
    Serial.println("SET_<pin_number>_OFF - Sets the specified pin to LOW.");
    Serial.println("READ_CHANNEL_<channel_number> - Reads the voltage of the specified channel(1-8).");
    Serial.println("READ_TEMPERATURE - Reads the temperature from the onboard sensor.");
    Serial.println("START_CONTINUOUS - Starts continuous measurements.");
    Serial.println("STOP_CONTINUOUS - Stops continuous measurements.");
    Serial.println("READ_CURRENT - Reads the current from the single channel.");
    Serial.println("VERSION - Returns the firmware version.");
  } else if (command.equals("VERSION")) {
    Serial.print("Firmware Version: ");
    Serial.println(FIRMWARE_VERSION);
  } else if (command.equals("START_CONTINUOUS")) {
    continuousMode = true;
    Serial.println("Continuous mode started");
  } else if (command.equals("STOP_CONTINUOUS")) {
    continuousMode = false;
    Serial.println("Continuous mode stopped");
  } else if (command.equals("MEAS:VOLT:CHAN1?")) {
    Serial.print("Channel 0 Voltage: ");
    Serial.println(readChannelVoltage(0), 4);
  } else if (command.equals("MEAS:VOLT:CHAN2?")) {
    Serial.print("Channel 1 Voltage: ");
    Serial.println(readChannelVoltage(1), 4);
  } else if (command.equals("MEAS:VOLT:CHAN3?")) {
    Serial.print("Channel 2 Voltage: ");
    Serial.println(readChannelVoltage(2), 4);
  } else if (command.equals("MEAS:VOLT:CHAN4?")) {
    Serial.print("Channel 3 Voltage: ");
    Serial.println(readChannelVoltage(3), 4);
  } else if (command.equals("MEAS:VOLT:CHAN5?")) {
    Serial.print("Channel 4 Voltage: ");
    Serial.println(readChannelVoltage(4), 4);
  } else if (command.equals("MEAS:VOLT:CHAN6?")) {
    Serial.print("Channel 5 Voltage: ");
    Serial.println(readChannelVoltage(5), 4);
  } else if (command.equals("MEAS:VOLT:CHAN7?")) {
    Serial.print("Channel 6 Voltage: ");
    Serial.println(readChannelVoltage(6), 4);
  } else if (command.equals("MEAS:VOLT:CHAN8?")) {
    Serial.print("Channel 7 Voltage: ");
    Serial.println(readChannelVoltage(7), 4);
  } else if (command.equals("MEAS:CURR?")) {
    float averagedCurrent = readCurrentAverage();
    Serial.println(averagedCurrent, 4);
  } else if (command.startsWith("READ_CHANNEL_")) {
    int channel = command.charAt(13) - '0';
    if (isValidChannel(channel)) {
      float voltage = readChannelVoltage(channel);
      Serial.print("Channel ");
      Serial.print(channel);
      Serial.print(": ");
      Serial.print(voltage, 4);
      Serial.println(" V");
    } else {
      Serial.println("Invalid channel");
    }
  } else if (command.equals("MEAS:TEMP?")) {
    float temperature = readTemperature();
    Serial.print("Temperature: ");
    Serial.print(temperature);
    Serial.println(" °C");
  }
}

void sendContinuousMeasurements() {
  String response = "";
  for (int i = 0; i < 8; i++) {
    response += "CH_";
    response += String(i);
    response += ": ";
    response += String(readChannelVoltage(i), 4);
    response += "V, ";
  }
  response.trim();
  Serial.println(response);
}
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

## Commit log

2024-10-16 added serial com functionality and corrected resistor values
    [main.ino]
2024-10-17 Added docs
    [BOM.ods]
2024-10-18 Added libiraries and updated testing status for temperature
2024-10-20 commented unnecessary serial prints
2024-10-22 added enclosure .stl files
    [ardudaqcase-bot.stl, ardudaqcase_top.stl]
2024-10-26 added multichannel support for voltage divider resistors
2024-11-13 Create readme.md
    added a readme to enclosure directory
2025-02-06 updated the desktop app and main board code
    desktop app: change the way a graph is display to lower the delays
    uno code: changed the commands to scpi format
2025-02-27 fixed latency and and data missmatch glitch
    [main.py]
2025-03-01 fixed the linux com port disconnect bug
    [main.py]
2025-03-04 added versioning of the board sw
2025-09-19 initial v2 firmware
    [BOM.ods]
2025-09-22 restructured directories for better ver overview
    [ardudaqcase-bot.stl, ardudaqcase_top.stl]
2025-09-26 updated fw for extra current channel via the onboard shunt
2025-10-07 updated readme and added bom
    [v2_BOM.csv]
